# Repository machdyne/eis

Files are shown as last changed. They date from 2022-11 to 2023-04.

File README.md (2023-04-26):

# Eis Computer

Eis is a small FPGA computer designed by Lone Dynamics Corporation.

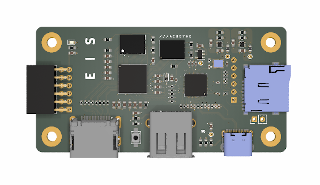
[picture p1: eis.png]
Eis Computer


This repo contains schematics, PCB layouts, pinouts, example firmware, gateware, documentation and a 3D printable case.

Find more information on the [Eis product page](https://machdyne.com/product/eis-computer/).

## Blinky 

Building the blinky example requires [Yosys](https://github.com/YosysHQ/yosys), [nextpnr-ice40](https://github.com/YosysHQ/nextpnr) and [IceStorm](https://github.com/YosysHQ/icestorm).

Assuming they are installed, you can simply type `make` to build the gateware, which will be written to output/blinky.bin. You can then connect the USB-C port to your computer and use the latest version of [ldprog](https://github.com/machdyne/ldprog) to write the gateware to the device.

## Programming

The RP2040 firmware, FPGA SRAM and flash MMOD can be programmed over the USB-C port.

Configure the FPGA SRAM:

```
$ ldprog -i -s blinky.bin
```

Program the flash MMOD:

```
$ ldprog -i -f blinky.bin
```

## Firmware

Eis ships with RP2040 [firmware](firmware) based on the [Müsli](https://github.com/machdyne/musli) firmware which allows it to communicate with [ldprog](https://github.com/machdyne/ldprog).

The firmware is responsible for initializing the system, [configuring and outputting the system clock](https://raspberrypi.github.io/pico-sdk-doxygen/group__hardware__clocks.html#details), and either configuring the FPGA or telling the FPGA to configure itself from the MMOD.

The system clock (CLK\_RP) is 48MHz by default.

The firmware can be updated by holding down the BOOTSEL button, connecting the USB-C port to your computer, and then dragging and dropping a new UF2 file to the device filesystem.

The firmware can be built from source or you can use the latest `eis.uf2` binary from the firmware directory.

## SOC

[Zucker](https://github.com/machdyne/zucker) is an experimental RISC-V SOC that supports Eis.

## Pinouts

 * [MMOD](https://github.com/machdyne/mmod)
 * [DDMI](https://github.com/machdyne/ddmi)

## License

The contents of this repo are released under the [Lone Dynamics Open License](LICENSE.md) with the following exceptions:

- The KiCad design files contain parts of the [kicad-pmod](https://github.com/mithro/kicad-pmod) library which is released under the [Apache License, Version 2.0](https://www.apache.org/licenses/LICENSE-2.0.html).

- The KiCad design files may contain symbols and footprints released under other licenses; please contact us if we've failed to give proper attribution.

Note: You can use these designs for commercial purposes but we ask that instead of producing exact clones, that you either replace our trademarks and logos with your own or add your own next to ours.

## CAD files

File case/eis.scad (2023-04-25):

/*
 * Eis Case
 * Copyright (c) 2022 Lone Dynamics Corporation. All rights reserved.
 *
 * required hardware:
 *  - 4 x M3 x 16mm countersunk bolts
 *  - 4 x M3 nuts
 *
 */

$fn = 100;

board_width = 40;
board_thickness = 1.5;
board_length = 80;
board_height = 1.6;
board_spacing = 2;

wall = 1.5;

top_height = 9;
bottom_height = 8;

//ldn_board();

translate([0,0,15])
	ldn_case_top();

//translate([0,0,-15])
//	ldn_case_bottom();

module ldn_board() {
	
	difference() {
		color([0,0.5,0])
			roundedcube(board_width,board_length,board_thickness, 2);
		translate([5, 5, -1]) cylinder(d=3.2, h=10);
		translate([5, 75, -1]) cylinder(d=3.2, h=10);
		translate([35, 5, -1]) cylinder(d=3.2, h=10);
		translate([35, 75, -1]) cylinder(d=3.2, h=10);
	}	
	
}

module ldn_case_top() {
	
	difference() {
				
		color([0.5,0.5,0.5])
			roundedcube(board_width+(wall*2),board_length+(wall*2),top_height,2.5);

		// cutouts
			
		translate([2,9,-2])
			roundedcube(board_width-1.25,board_length-15,9.25,2.5);

		translate([9,3,-2])
			roundedcube(board_width-15,board_length-3,9.25,2.5);
		
		translate([wall, wall, 0]) {
	
			// HDMI
			translate([30,19-(15.5/2),-1]) cube([30,15.5,6.2+1]);
		
			// USBA
			translate([30,43-(15/2),-1]) cube([30,15,7.2+1.05]);

			// USBC
			translate([30,64.25-(9.5/2),-1]) cube([30,9.5,3.5+1]);
		
			// SD
			translate([20-(15/2),70,-1]) cube([15,30,2+1]);

			// PMODA
			translate([20-(16/2),-10,-2]) cube([16,30,5.5+1.15]);

			// LED vent
			// translate([-5,25,4]) cube([30,1.5,1.5]);
			// translate([-5,20,4]) cube([30,1.5,1.5]);
			// translate([-5,15,4]) cube([30,1.5,1.5]);
				
			// bolt holes
			translate([5, 5, -21]) cylinder(d=3.5, h=40);
			translate([5, 75, -21]) cylinder(d=3.5, h=40);
			translate([35, 5, -20]) cylinder(d=3.5, h=40);
			translate([35, 75, -21]) cylinder(d=3.5, h=40);

			// flush mount bolt holes
			translate([5, 5, top_height-1]) cylinder(d=5, h=4);
			translate([5, 75, top_height-1]) cylinder(d=5, h=4);
			translate([35, 5, top_height-1]) cylinder(d=5, h=4);
			translate([35, 75, top_height-1]) cylinder(d=5, h=4);

			// eis text
			rotate(270)
				translate([-21,20-3,top_height-0.8])
					linear_extrude(1)
						text("E   I   S", size=6, halign="center",
							font="Ubuntu:style=Bold");

		}
		
	}	
}

module ldn_case_bottom() {
	
	difference() {
		color([0.5,0.5,0.5])
			roundedcube(board_width+(wall*2),board_length+(wall*2),bottom_height,2.5);
		
		// cutouts
		translate([3,10,1.5])
			roundedcube(board_width-3,board_length-17,10,2.5);
				
		translate([10.5,2.5,1.5])
			roundedcube(board_width-17.5,board_length-2,10,2.5);

		translate([wall, wall, 0]) {
			
		// board cutout
		translate([-0.25,-0.25,bottom_height-board_height])
			roundedcube(board_width+0.5,board_length+0.5,board_height+1,2);

		// bolt holes
		translate([5, 5, -11]) cylinder(d=3.2, h=25);
		translate([5, 75, -11]) cylinder(d=3.2, h=25);
		translate([35, 5, -11]) cylinder(d=3.2, h=25);
		translate([35, 75, -11]) cylinder(d=3.2, h=25);

		// nut holes
		translate([5, 5, -1]) cylinder(d=7, h=2.5+2, $fn=6);
		translate([5, 75, -1]) cylinder(d=7, h=2.5+2, $fn=6);
		translate([35, 5, -1]) cylinder(d=7, h=2.5+2, $fn=6);
		translate([35, 75, -1]) cylinder(d=7, h=2.5+2, $fn=6);

		}
		
	}	
}

// https://gist.github.com/tinkerology/ae257c5340a33ee2f149ff3ae97d9826
module roundedcube(xx, yy, height, radius)
{
    translate([0,0,height/2])
    hull()
    {
        translate([radius,radius,0])
        cylinder(height,radius,radius,true);

        translate([xx-radius,radius,0])
        cylinder(height,radius,radius,true);

        translate([xx-radius,yy-radius,0])
        cylinder(height,radius,radius,true);

        translate([radius,yy-radius,0])
        cylinder(height,radius,radius,true);
    }
}

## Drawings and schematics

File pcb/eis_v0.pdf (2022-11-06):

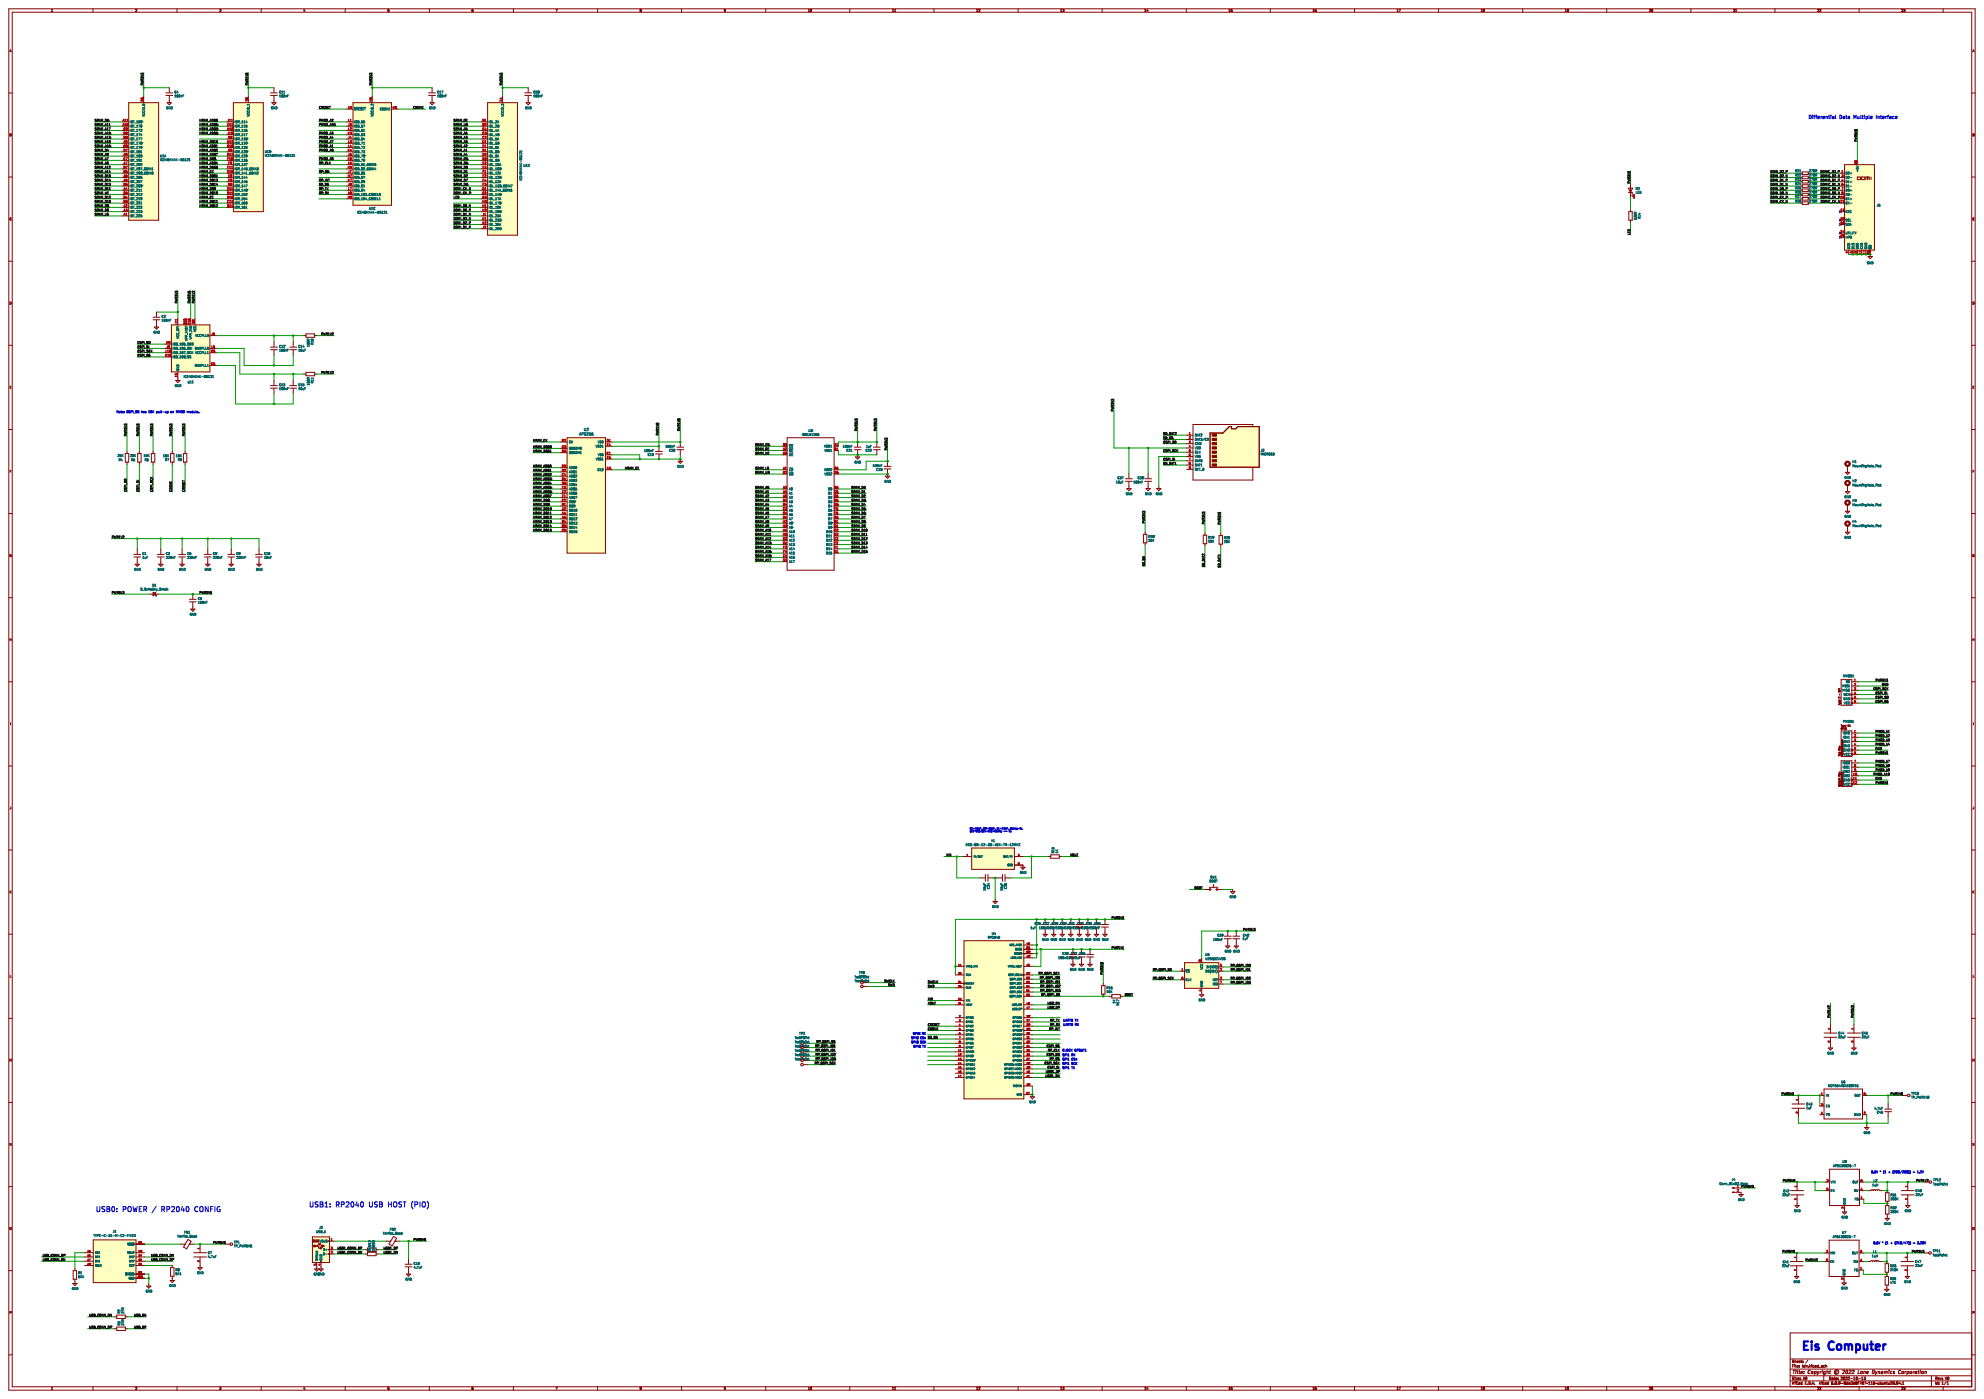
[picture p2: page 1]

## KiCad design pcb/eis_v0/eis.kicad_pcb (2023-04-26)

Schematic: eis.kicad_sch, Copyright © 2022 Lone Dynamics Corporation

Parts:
C1, C43: 1uF; C_0603_1608Metric
C2, C4, C6, C11, C12, C13, C17, C18: 100nF; C_0603_1608Metric
C3, C5, C8, C9: 220nF; C_0603_1608Metric
C7, C16: 4.7uF; C_0603_1608Metric
C10: 10nF; C_0603_1608Metric
C14, C15: 10uF; C_0603_1608Metric
C19, C20, C21, C23: 100nF; R_0603_1608Metric
C22: 1uF; R_0603_1608Metric
C24, C25: 15pF; C_0402_1005Metric
C26, C34, C40: 1uF; C_0402_1005Metric
C27, C28, C29, C30, C31, C32, C33, C35, C36, C39: 100nF; C_0402_1005Metric
C37: 10uF; R_0402_1005Metric
C38: 100nF; R_0402_1005Metric
C41, C42, C44, C46, C47, C48: 22uF; C_0603_1608Metric
C45: 4.7uF; R_0603_1608Metric
D1: D_Schottky_Small; D_0603_1608Metric
D2: LED; LED_0603_1608Metric
FB1, FB2: Ferrite_Bead; R_0603_1608Metric
H1, H2, H3, H4: MountingHole_Pad; MountingHole_3.2mm_M3_Pad
J1: TYPE-C-31-M-12-FIXED; USB_C_Receptacle_HRO_TYPE-C-31-M-12; PARTREV A
J2: USB_A; USB_A_Stewart_SS-52100-001_Horizontal
J3: MICROSD; SDCARD
J4: Conn_01x02_Male; PinHeader_1x02_P2.54mm_Vertical
J5: HDMI_TE_1827059-3-FIXED
L1, L2: 1uH; L_0603_1608Metric
MMOD1: PMOD-Device-x1-Type-2-SPI; PinSocket_1x06_P2.54mm_Horizontal
PMOD1: PMOD-Device-x2-Type-1A-GPIO; PMOD_2x06_HOST
R1, R8: 5K1; R_0603_1608Metric
R2, R3: 27R; R_0402_1005Metric
R4, R5, R18, R19, R20: 20K; R_0402_1005Metric
R6, R7, R9, R16: 10K; R_0402_1005Metric
R10, R11: 100R; R_0603_1608Metric
R12, R13: 22R; R_0402_1005Metric
R14: 536R; R_0603_1608Metric
R15: 1K; R_0402_1005Metric
R17: 1K; R_0603_1608Metric
R21, R22, R23, R24, R25, R26, R27, R28: 270R; R_0402_1005Metric
R29: 210K; R_0603_1608Metric
R30: 47K; R_0603_1608Metric
R31, R32: 200K; R_0603_1608Metric
SW1: BOOT; Button_2P_3x4mm
TP1: TP_PWR5V0; TestPoint_THTPad_D1.0mm_Drill0.5mm
TP2, TP3, TP4, TP5, TP6, TP7, TP8, TP9: TestPoint; TestPoint_Pad_1.0x1.0mm
TP10: TP_PWR1V8; TestPoint_THTPad_D1.0mm_Drill0.5mm
TP11, TP12: TestPoint; TestPoint_THTPad_D1.0mm_Drill0.5mm
U1: ICE40HX4K-BG121; BGA-121_9.0x9.0mm_Layout11x11_P0.8mm_Ball0.4mm_Pad0.35mm_NS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
U2: APS256; APS256_BGA_24
U3: IS61WV256; BGA48C75P8X6_800X600X120N
U4: RP2040; RP2040-QFN-56-OFFICIAL; PARTREV 1.6.1
U5: W25Q32JVSS; SOIC-8_3.9x4.9mm_P1.27mm
U6: NCP164ASN180T1G; TSOP-5_1.65x3.05mm_P0.95mm
U7, U8: AP61300Z6-7; SOT-563
Y1: ECS-80-12-33-JGN-TR-12MHZ; XTAL_ECS-240-8-33-AGN-TR

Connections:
/BOOT: R17.1, SW1.1
/CDONE: R7.1, U1.K8 (CDONE), U4.5 (GPIO3)
/CRESET: R9.1, U1.L9 (~CRESET), U4.4 (GPIO2)
/CSPI_SCK: J3.5 (CLK), MMOD1.3 (MISO), R6.1, U1.L10 (IOB_107_SCK), U4.38 (GPIO26/ADC0)
/CSPI_SI: J3.7 (DAT0), MMOD1.4 (SCK), R5.1, U1.J9 (IOB_106_SDI), U4.39 (GPIO27/ADC1)
/CSPI_SO: J3.3 (CMD), MMOD1.5 (GND), R4.1, U1.K9 (IOB_105_SDO), U4.36 (GPIO24)
/CSPI_SS: MMOD1.6 (VCC), U1.K10 (IOB_108_SS), U4.34 (GPIO22)
/DDMIC_CK_N: J5.12 (CK-), R28.2
/DDMIC_CK_P: J5.10 (CK+), R27.2
/DDMIC_D0_N: J5.9 (D0-), R26.2
/DDMIC_D0_P: J5.7 (D0+), R25.2
/DDMIC_D1_N: J5.6 (D1-), R24.2
/DDMIC_D1_P: J5.4 (D1+), R23.2
/DDMIC_D2_N: J5.3 (D2-), R22.2
/DDMIC_D2_P: J5.1 (D2+), R21.2
/DDMI_CK_N: R28.1, U1.G1 (IOL_14A_GBIN6)
/DDMI_CK_P: R27.1, U1.G2 (IOL_14B)
/DDMI_D0_N: R26.1, U1.H1 (IOL_18A)
/DDMI_D0_P: R25.1, U1.H2 (IOL_18B)
/DDMI_D1_N: R24.1, U1.J1 (IOL_23A)
/DDMI_D1_P: R23.1, U1.J2 (IOL_25B)
/DDMI_D2_N: R22.1, U1.K1 (IOL_23B)
/DDMI_D2_P: R21.1, U1.K2 (IOL_25A)
/HRAM_ADQ0: U1.J11 (IOR_114), U2.D3 (ADQ0)
/HRAM_ADQ1: U1.G10 (IOR_120), U2.D2 (ADQ1)
/HRAM_ADQ2: U1.G9 (IOR_128), U2.C4 (ADQ2)
/HRAM_ADQ3: U1.H10 (IOR_116), U2.D4 (ADQ3)
/HRAM_ADQ4: U1.F9 (IOR_137), U2.D5 (ADQ4)
/HRAM_ADQ5: U1.K11 (IOR_115), U2.E3 (ADQ5)
/HRAM_ADQ6: U1.J10 (IOR_117), U2.E2 (ADQ6)
/HRAM_ADQ7: U1.G11 (IOR_129), U2.E1 (ADQ7)
/HRAM_CE: U1.D10 (IOR_154), U2.A3 (CE#)
/HRAM_CK: U1.E10 (IOR_141_GBIN2), U2.B2 (CK)
/HRAM_DQ8: U1.F10 (IOR_136), U2.C2 (DQ8)
/HRAM_DQ9: U1.E11 (IOR_148), U2.B1 (DQ9)
/HRAM_DQ10: U1.D11 (IOR_152), U2.A2 (DQ10)
/HRAM_DQ11: U1.C11 (IOR_160), U2.A4 (DQ11)
/HRAM_DQ12: U1.B11 (IOR_161), U2.A5 (DQ12)
/HRAM_DQ13: U1.E8 (IOR_146), U2.B4 (DQ13)
/HRAM_DQ14: U1.D9 (IOR_147), U2.B5 (DQ14)
/HRAM_DQ15: U1.H11 (IOR_119), U2.C5 (DQ15)
/HRAM_DQS0: U1.F11 (IOR_140_GBIN3), U2.C3 (DQSDM0)
/HRAM_DQS1: U1.E9 (IOR_144), U2.B3 (DQSDM1)
/LED: R14.1, U1.G3 (IOL_17A)
/PMOD_A1: PMOD1.1 (IOA0), U1.L4 (IOB_72)
/PMOD_A2: PMOD1.2 (IOA1), U1.L1 (IOB_56)
/PMOD_A3: PMOD1.3 (IOA2), U1.K3 (IOB_63)
/PMOD_A4: PMOD1.4 (IOA3), U1.J4 (IOB_64)
/PMOD_A7: PMOD1.7 (IOB0), U1.L3 (IOB_71)
/PMOD_A8: PMOD1.8 (IOB1), U1.K5 (IOB_79)
/PMOD_A9: PMOD1.9 (IOB2), U1.K4 (IOB_73)
/PMOD_A10: PMOD1.10 (IOB3), U1.J3 (IOB_57)
/PWR1V1: C30.1, C32.1, C34.1, U4.23 (DVDD), U4.45 (VREG_VOUT), U4.50 (DVDD)
/PWR1V2: C1.1, C3.1, C5.1, C8.1, C9.1, C10.1, C44.1, C48.1, L2.2, R10.1, R11.1, R31.1, TP12.1, U1.D4 (VCC), U1.D8 (VCC), U1.H4 (VCC), U1.H8 (VCC), U7.5 (EN), U8.6 (OUT)
/PWR1V8: C11.1, C19.2, C20.2, C45.2, TP10.1, U1.F8 (VCCIO_1), U2.D1 (VDD), U2.E4 (VDD1), U6.5 (OUT)
/PWR2V5: C6.1, D1.1 (K), U1.C10 (VPP_2V5)
/PWR3V3: C2.1, C4.1, C17.1, C18.1, C21.2, C22.2, C23.2, C26.1, C27.1, C28.1, C29.1, C31.1, C33.1, C35.1, C36.1, C37.1, C38.1, C39.1, C40.1, C43.1, C46.1, C47.1, D1.2 (A), D2.2 (A), J3.4 (VDD), L1.2, MMOD1.1 (SS), PMOD1.6 (VCC), PMOD1.12 (VCC), R4.2, R5.2, R6.2, R7.2, R9.2, R16.1, R18.1, R19.1, R20.1, R29.1, TP11.1, U1.D6 (VCCIO_0), U1.E4 (VCCIO_3), U1.G4 (VCCIO_3), U1.H6 (VCCIO_2), U1.L11 (VCC_SPI), U3.D6 (VDD2), U3.E1 (VDD1), U4.1 (IOVDD), U4.10 (IOVDD), U4.22 (IOVDD), U4.26 (RUN), U4.33 (IOVDD), U4.42 (IOVDD), U4.43 (ADC_AVDD), U4.44 (VREG_VIN), U4.48 (USB_VDD), U4.49 (IOVDD), U5.8 (VCC), U6.1 (IN), U6.3 (EN), U7.6 (OUT)
/PWR5V0: C7.1, C16.1, C41.1, C42.1, FB1.1, FB2.1, J4.1, J5.18 (+5V), TP1.1, U7.3 (VIN), U8.3 (VIN), U8.5 (EN)
/RP_CLK: U1.L5 (IOB_81_GBIN5), U4.35 (GPIO23)
/RP_INT: U1.K7 (IOB_89), U4.29 (GPIO18)
/RP_QSPI_IO0: TP3.1, U4.53 (QSPI_SD0), U5.5 (DI(IO0))
/RP_QSPI_IO1: TP4.1, U4.55 (QSPI_SD1), U5.2 (DO(IO1))
/RP_QSPI_IO2: TP5.1, U4.54 (QSPI_SD2), U5.3 (IO2)
/RP_QSPI_IO3: TP6.1, U4.51 (QSPI_SD3), U5.7 (IO3)
/RP_QSPI_SCK: TP7.1, U4.52 (QSPI_SCLK), U5.6 (CLK)
/RP_QSPI_SS: R16.2, R17.2, TP2.1, U4.56 (QSPI_CSN), U5.1 (~CS)
/RP_RX: U1.L8 (IOB_103_CBSEL0), U4.28 (GPIO17)
/RP_SS: U1.J7 (IOB_86), U4.37 (GPIO25)
/RP_TX: U1.L7 (IOB_94), U4.27 (GPIO16)
/SD_DAT1: J3.8 (DAT1), R20.2
/SD_DAT2: J3.1 (DAT2), R19.2
/SD_SS: J3.2 (DAT3/CD), R18.2, U1.J8 (IOB_91), U4.7 (GPIO5)
/SRAM_A0: U1.C1 (IOL_5B), U3.A3 (A0)
/SRAM_A1: U1.D1 (IOL_8B), U3.A4 (A1)
/SRAM_A2: U1.E1 (IOL_8A), U3.A5 (A2)
/SRAM_A3: U1.C2 (IOL_5A), U3.B3 (A3)
/SRAM_A4: U1.D2 (IOL_9A), U3.B4 (A4)
/SRAM_A5: U1.C4 (IOL_4A), U3.C3 (A5)
/SRAM_A6: U1.C3 (IOL_4B), U3.C4 (A6)
/SRAM_A7: U1.C7 (IOT_191), U3.D4 (A7)
/SRAM_A8: U1.A7 (IOT_192), U3.H2 (A8)
/SRAM_A9: U1.A8 (IOT_190), U3.H3 (A9)
/SRAM_A10: U1.A9 (IOT_178), U3.H4 (A10)
/SRAM_A11: U1.A10 (IOT_170), U3.H5 (A11)
/SRAM_A12: U1.B7 (IOT_197_GBIN1), U3.G3 (A12)
/SRAM_A13: U1.B8 (IOT_177), U3.G4 (A13)
/SRAM_A14: U1.B6 (IOT_198_GBIN0), U3.F3 (A14)
/SRAM_A15: U1.B9 (IOT_174), U3.F4 (A15)
/SRAM_A16: U1.C8 (IOT_179), U3.E4 (A16)
/SRAM_A17: U1.C9 (IOT_172), U3.D3 (A17)
/SRAM_CS: U1.D3 (IOL_9B), U3.B5 (~CS)
/SRAM_D0: U1.E3 (IOL_10B), U3.B6 (D0)
/SRAM_D1: U1.F1 (IOL_12A), U3.C5 (D1)
/SRAM_D2: U1.F2 (IOL_12B), U3.C6 (D2)
/SRAM_D3: U1.F3 (IOL_13B_GBIN7), U3.D5 (D3)
/SRAM_D4: U1.D7 (IOT_181), U3.E5 (D4)
/SRAM_D5: U1.E2 (IOL_10A), U3.F5 (D5)
/SRAM_D6: U1.A11 (IOT_168), U3.F6 (D6)
/SRAM_D7: U1.F4 (IOL_13A), U3.G6 (D7)
/SRAM_D8: U1.A2 (IOT_222), U3.B1 (D8)
/SRAM_D9: U1.A3 (IOT_223), U3.C1 (D9)
/SRAM_D10: U1.B3 (IOT_221), U3.C2 (D10)
/SRAM_D11: U1.A4 (IOT_211), U3.D2 (D11)
/SRAM_D12: U1.B4 (IOT_219), U3.E2 (D12)
/SRAM_D13: U1.B5 (IOT_208), U3.F2 (D13)
/SRAM_D14: U1.A5 (IOT_207), U3.F1 (D14)
/SRAM_D15: U1.A6 (IOT_206), U3.G1 (D15)
/SRAM_LB: U1.A1 (IOT_225), U3.A1 (~LB)
/SRAM_OE: U1.B1 (IOL_2A), U3.A2 (~OE)
/SRAM_UB: U1.B2 (IOL_2B), U3.B2 (~UB)
/SRAM_WE: U1.D5 (IOT_212), U3.G5 (~WE)
/SWCLK: TP8.1, U4.24 (SWCLK)
/SWD: TP9.1, U4.25 (SWD)
/USB1_CONN_DN: J2.2 (D-), R13.1
/USB1_CONN_DP: J2.3 (D+), R12.1
/USB1_DN: R13.2, U4.41 (GPIO29/ADC3)
/USB1_DP: R12.2, U4.40 (GPIO28/ADC2)
/USB_CONN_DN: J1.A7 (DN1), J1.B7 (DN2), R2.1
/USB_CONN_DP: J1.A6 (DP1), J1.B6 (DP2), R3.1
/USB_DN: R2.2, U4.46 (USB_DM)
/USB_DP: R3.2, U4.47 (USB_DP)
/XIN: C24.2, U4.20 (XIN), Y1.1 (IN/OUT)
/XOUT: R15.2, U4.21 (XOUT)
GND: C1.2, C2.2, C3.2, C4.2, C5.2, C6.2, C7.2, C8.2, C9.2, C10.2, C11.2, C16.2, C17.2, C18.2, C19.1, C20.1, C21.1, C22.1, C23.1, C24.1, C25.2, C26.2, C27.2, C28.2, C29.2, C30.2, C31.2, C32.2, C33.2, C34.2, C35.2, C36.2, C37.2, C38.2, C39.2, C40.2, C41.2, C42.2, C43.2, C44.2, C45.1, C46.2, C47.2, C48.2, H1.1, H2.1, H3.1, H4.1, J1.A1 (GND), J1.A12 (GND), J1.B1 (GND), J1.B12 (GND), J1.S1 (SHIELD), J1.S2 (SHIELD), J1.S3 (SHIELD), J1.S4 (SHIELD), J2.4 (GND), J2.5 (Shield), J3.6 (VSS), J4.2, J5.2 (D2S), J5.5 (D1S), J5.8 (D0S), J5.11 (CKS), J5.17 (GND), J5.S1 (SH), J5.S2 (SH), J5.S3 (SH), J5.S4 (SH), MMOD1.2 (MOSI), PMOD1.5 (GND), PMOD1.11 (GND), R1.2, R8.2, R30.2, R32.2, SW1.2, U1.E5 (GND), U1.E6 (GND), U1.E7 (GND), U1.F5 (GND), U1.F6 (GND), U1.F7 (GND), U1.G5 (GND), U1.G6 (GND), U1.G7 (GND), U1.H5 (GND), U2.C1 (VSS), U2.E5 (VSS1), U3.D1 (VSS1), U3.E6 (VSS2), U4.19 (TESTEN), U4.57 (GND), U5.4 (GND), U6.2 (GND), U7.2 (GND), U8.2 (GND), Y1.2 (GND), Y1.4 (GND)
unnamed: C12.1, C14.1, R10.2, U1.J6 (VCCPLL0)
unnamed: C12.2, C14.2, U1.L6 (GNDPLL0)
unnamed: C13.1, C15.1, R11.2, U1.C6 (VCCPLL1)
unnamed: C13.2, C15.2, U1.C5 (GNDPLL1)
unnamed: C25.1, R15.1, Y1.3 (OUT/IN)
unnamed: D2.1 (K), R14.2
unnamed: FB1.2, J1.A4 (VBUS), J1.A9 (VBUS), J1.B4 (VBUS), J1.B9 (VBUS)
unnamed: FB2.2, J2.1 (VBUS)
unnamed: J1.A5 (CC1), R1.1
unnamed: J1.B5 (CC2), R8.1
unnamed: L1.1, U7.4 (SW)
unnamed: L2.1, U8.4 (SW)
unnamed: R29.2, R30.1, U7.1 (FB)
unnamed: R31.2, R32.1, U8.1 (FB)

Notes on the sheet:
SPI1 RX
CLOCK GPOUT1
UART0 RX
USB1: RP2040 USB HOST (PIO)
0.6V * (1 + (210/47)) = 3.28V
SPI1 CSn
C1=15pF, C2=15pF, CL=12pF, Cstray=5, (C1*C2)/(C1+C2)+Cstray == CL
SPI0 CSn
UART0 TX
0.6V * (1 + (200/200)) = 1.2V
Differential Data Multiple Interface
USB0: POWER / RP2040 CONFIG
SPI0 TX
SPI1 TX
Note: CSPI_SS has 10K pull-up on MMOD module.
SPI0 RX
SPI1 SCK
SPI0 SCK
Eis Computer

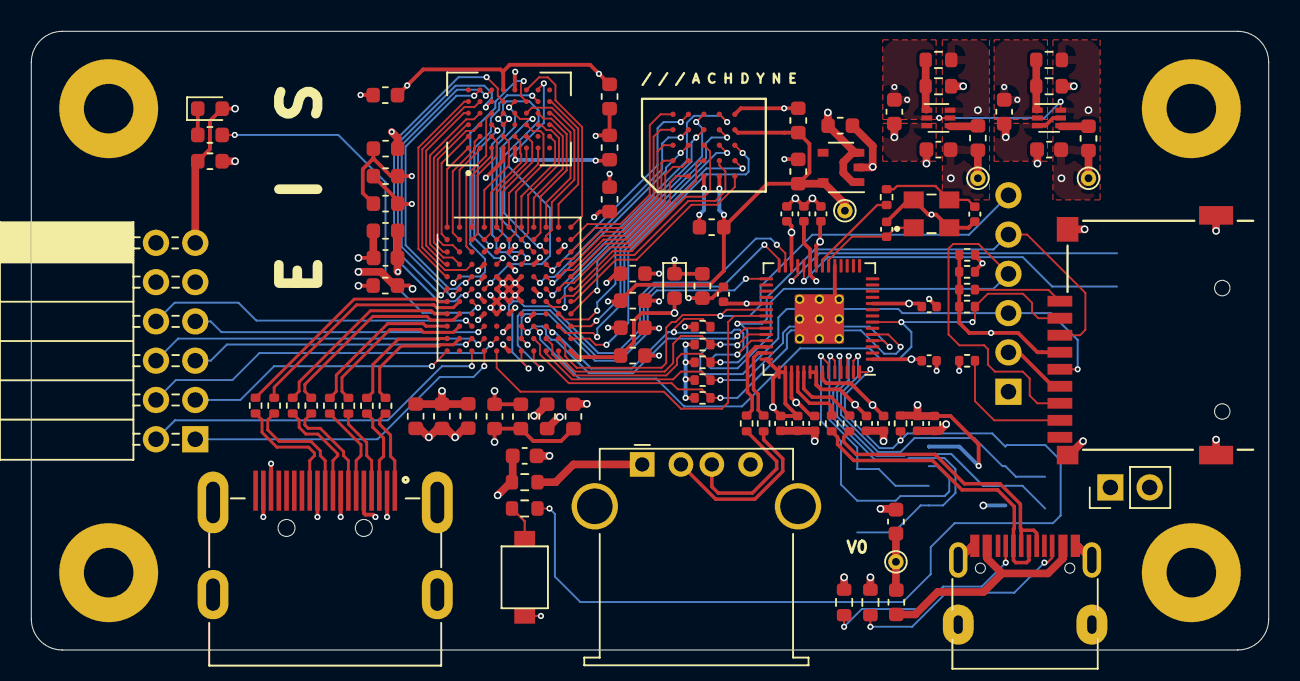
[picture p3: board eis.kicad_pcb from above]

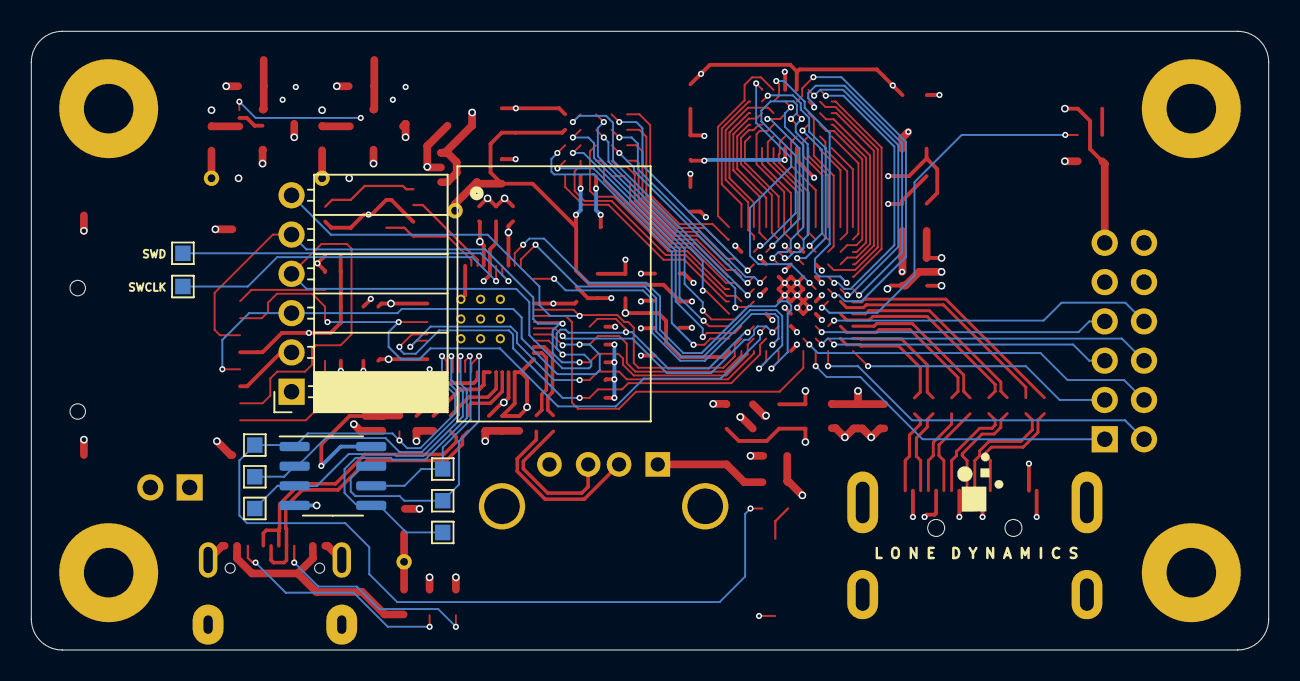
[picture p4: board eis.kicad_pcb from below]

Board: 4 copper layers, 80.0 x 40.0 mm, 120 parts (11 on the bottom side), 138 nets.

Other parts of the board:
CONFIG-MMOD: LD-MMOD

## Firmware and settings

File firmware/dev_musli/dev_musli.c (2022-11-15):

/**
 * Copyright (c) 2020 Raspberry Pi (Trading) Ltd.
 * Copyright (c) 2022 Lone Dynamics Corporation <info@lonedynamics.com>
 *
 * SPDX-License-Identifier: BSD-3-Clause
 *
 * Musli USB Device Software
 *
 */

#define MUSLI_SPI_RX_PIN	24
#define MUSLI_SPI_CSN_PIN	22
#define MUSLI_SPI_SCK_PIN	26
#define MUSLI_SPI_TX_PIN	27

#define MUSLI_CMD_READY 0x00
#define MUSLI_CMD_INIT 0x01

#define MUSLI_CMD_GPIO_SET_DIR 0x10
#define MUSLI_CMD_GPIO_DISABLE_PULLS 0x11
#define MUSLI_CMD_GPIO_PULL_UP 0x12
#define MUSLI_CMD_GPIO_PULL_DOWN 0x13

#define MUSLI_CMD_GPIO_GET 0x20
#define MUSLI_CMD_GPIO_PUT 0x21

#define MUSLI_CMD_SPI_READ 0x80
#define MUSLI_CMD_SPI_WRITE 0x81
#define MUSLI_CMD_CFG_PIO_SPI 0x8f

#define MUSLI_CMD_REBOOT 0xf0

#define SPI_MODE_HW 1
#define SPI_MODE_PIO 2

#include <stdio.h>
#include <strings.h>

// Pico
#include "pico/stdlib.h"
#include "hardware/spi.h"
#include "hardware/watchdog.h"
#include "pico/stdlib.h"
#include "pico/binary_info.h"
#include "pio_spi.h"

uint8_t spi_mode = SPI_MODE_HW;

void init_ldprog(void);
void init_gpio(void);
void init_pio_spi(void);
void pio_spi_cfg(uint8_t pin_sck, uint8_t pin_mosi, uint8_t pin_miso);

uint8_t spi_pio_offset;

pio_spi_inst_t spi_pio = {
	.pio = pio0,
	.sm = 0
};

// For memcpy
#include <string.h>

// Include descriptor struct definitions
#include "usb_common.h"
// USB register definitions from pico-sdk
#include "hardware/regs/usb.h"
// USB hardware struct definitions from pico-sdk
#include "hardware/structs/usb.h"
// For interrupt enable and numbers
#include "hardware/irq.h"
// For resetting the USB controller
#include "hardware/resets.h"

// Device descriptors
#include "dev_musli.h"

#define usb_hw_set hw_set_alias(usb_hw)
#define usb_hw_clear hw_clear_alias(usb_hw)

// Function prototypes for our device specific endpoint handlers defined
// later on
void ep0_in_handler(uint8_t *buf, uint16_t len);
void ep0_out_handler(uint8_t *buf, uint16_t len);
void ep1_out_handler(uint8_t *buf, uint16_t len);
void ep2_in_handler(uint8_t *buf, uint16_t len);

// Global device address
static bool should_set_address = false;
static uint8_t dev_addr = 0;
static volatile bool configured = false;

// Global data buffer for EP0
static uint8_t ep0_buf[64];

// Struct defining the device configuration
static struct usb_device_configuration dev_config = {
        .device_descriptor = &device_descriptor,
        .interface_descriptor = &interface_descriptor,
        .config_descriptor = &config_descriptor,
        .lang_descriptor = lang_descriptor,
        .descriptor_strings = descriptor_strings,
        .endpoints = {
                {
                        .descriptor = &ep0_out,
                        .handler = &ep0_out_handler,
                        .endpoint_control = NULL, // NA for EP0
                        .buffer_control = &usb_dpram->ep_buf_ctrl[0].out,
                        // EP0 in and out share a data buffer
                        .data_buffer = &usb_dpram->ep0_buf_a[0],
                },
                {
                        .descriptor = &ep0_in,
                        .handler = &ep0_in_handler,
                        .endpoint_control = NULL, // NA for EP0,
                        .buffer_control = &usb_dpram->ep_buf_ctrl[0].in,
                        // EP0 in and out share a data buffer
                        .data_buffer = &usb_dpram->ep0_buf_a[0],
                },
                {
                        .descriptor = &ep1_out,
                        .handler = &ep1_out_handler,
                        // EP1 starts at offset 0 for endpoint control
                        .endpoint_control = &usb_dpram->ep_ctrl[0].out,
                        .buffer_control = &usb_dpram->ep_buf_ctrl[1].out,
                        // First free EPX buffer
                        .data_buffer = &usb_dpram->epx_data[0 * 64],
                },
                {
                        .descriptor = &ep2_in,
                        .handler = &ep2_in_handler,
                        .endpoint_control = &usb_dpram->ep_ctrl[1].in,
                        .buffer_control = &usb_dpram->ep_buf_ctrl[2].in,
                        // Second free EPX buffer
                        .data_buffer = &usb_dpram->epx_data[1 * 64],
                }
        }
};

/**
 * @brief Given an endpoint address, return the usb_endpoint_configuration of that endpoint. Returns NULL
 * if an endpoint of that address is not found.
 *
 * @param addr
 * @return struct usb_endpoint_configuration*
 */
struct usb_endpoint_configuration *usb_get_endpoint_configuration(uint8_t addr) {
    struct usb_endpoint_configuration *endpoints = dev_config.endpoints;
    for (int i = 0; i < USB_NUM_ENDPOINTS; i++) {
        if (endpoints[i].descriptor && (endpoints[i].descriptor->bEndpointAddress == addr)) {
            return &endpoints[i];
        }
    }
    return NULL;
}

/**
 * @brief Given a C string, fill the EP0 data buf with a USB string descriptor for that string.
 *
 * @param C string you would like to send to the USB host
 * @return the length of the string descriptor in EP0 buf
 */
uint8_t usb_prepare_string_descriptor(const unsigned char *str) {
    // 2 for bLength + bDescriptorType + strlen * 2 because string is unicode. i.e. other byte will be 0
    uint8_t bLength = 2 + (strlen((const char *)str) * 2);
    static const uint8_t bDescriptorType = 0x03;

    volatile uint8_t *buf = &ep0_buf[0];
    *buf++ = bLength;
    *buf++ = bDescriptorType;

    uint8_t c;

    do {
        c = *str++;
        *buf++ = c;
        *buf++ = 0;
    } while (c != '\0');

    return bLength;
}

/**
 * @brief Take a buffer pointer located in the USB RAM and return as an offset of the RAM.
 *
 * @param buf
 * @return uint32_t
 */
static inline uint32_t usb_buffer_offset(volatile uint8_t *buf) {
    return (uint32_t) buf ^ (uint32_t) usb_dpram;
}

/**
 * @brief Set up the endpoint control register for an endpoint (if applicable. Not valid for EP0).
 *
 * @param ep
 */
void usb_setup_endpoint(const struct usb_endpoint_configuration *ep) {
    printf("Set up endpoint 0x%x with buffer address 0x%p\n", ep->descriptor->bEndpointAddress, ep->data_buffer);

    // EP0 doesn't have one so return if that is the case
    if (!ep->endpoint_control) {
        return;
    }

    // Get the data buffer as an offset of the USB controller's DPRAM
    uint32_t dpram_offset = usb_buffer_offset(ep->data_buffer);
    uint32_t reg = EP_CTRL_ENABLE_BITS
                   | EP_CTRL_INTERRUPT_PER_BUFFER
                   | (ep->descriptor->bmAttributes << EP_CTRL_BUFFER_TYPE_LSB)
                   | dpram_offset;
    *ep->endpoint_control = reg;
}

/**
 * @brief Set up the endpoint control register for each endpoint.
 *
 */
void usb_setup_endpoints() {
    const struct usb_endpoint_configuration *endpoints = dev_config.endpoints;
    for (int i = 0; i < USB_NUM_ENDPOINTS; i++) {
        if (endpoints[i].descriptor && endpoints[i].handler) {
            usb_setup_endpoint(&endpoints[i]);
        }
    }
}

/**
 * @brief Set up the USB controller in device mode, clearing any previous state.
 *
 */
void usb_device_init() {
    // Reset usb controller
    reset_block(RESETS_RESET_USBCTRL_BITS);
    unreset_block_wait(RESETS_RESET_USBCTRL_BITS);

    // Clear any previous state in dpram just in case
    memset(usb_dpram, 0, sizeof(*usb_dpram)); // <1>

    // Enable USB interrupt at processor
    irq_set_enabled(USBCTRL_IRQ, true);

    // Mux the controller to the onboard usb phy
    usb_hw->muxing = USB_USB_MUXING_TO_PHY_BITS | USB_USB_MUXING_SOFTCON_BITS;

    // Force VBUS detect so the device thinks it is plugged into a host
    usb_hw->pwr = USB_USB_PWR_VBUS_DETECT_BITS | USB_USB_PWR_VBUS_DETECT_OVERRIDE_EN_BITS;

    // Enable the USB controller in device mode.
    usb_hw->main_ctrl = USB_MAIN_CTRL_CONTROLLER_EN_BITS;

    // Enable an interrupt per EP0 transaction
    usb_hw->sie_ctrl = USB_SIE_CTRL_EP0_INT_1BUF_BITS; // <2>

    // Enable interrupts for when a buffer is done, when the bus is reset,
    // and when a setup packet is received
    usb_hw->inte = USB_INTS_BUFF_STATUS_BITS |
                   USB_INTS_BUS_RESET_BITS |
                   USB_INTS_SETUP_REQ_BITS;

    // Set up endpoints (endpoint control registers)
    // described by device configuration
    usb_setup_endpoints();

    // Present full speed device by enabling pull up on DP
    usb_hw_set->sie_ctrl = USB_SIE_CTRL_PULLUP_EN_BITS;
}

/**
 * @brief Given an endpoint configuration, returns true if the endpoint
 * is transmitting data to the host (i.e. is an IN endpoint)
 *
 * @param ep, the endpoint configuration
 * @return true
 * @return false
 */
static inline bool ep_is_tx(struct usb_endpoint_configuration *ep) {
    return ep->descriptor->bEndpointAddress & USB_DIR_IN;
}

/**
 * @brief Starts a transfer on a given endpoint.
 *
 * @param ep, the endpoint configuration.
 * @param buf, the data buffer to send. Only applicable if the endpoint is TX
 * @param len, the length of the data in buf (this example limits max len to one packet - 64 bytes)
 */
void usb_start_transfer(struct usb_endpoint_configuration *ep, uint8_t *buf, uint16_t len) {
    // We are asserting that the length is <= 64 bytes for simplicity of the example.
    // For multi packet transfers see the tinyusb port.
    assert(len <= 64);

//    printf("Start transfer of len %d on ep addr 0x%x\n", len, ep->descriptor->bEndpointAddress);

    // Prepare buffer control register value
    uint32_t val = len | USB_BUF_CTRL_AVAIL;

    if (ep_is_tx(ep)) {
        // Need to copy the data from the user buffer to the usb memory
        memcpy((void *) ep->data_buffer, (void *) buf, len);
        // Mark as full
        val |= USB_BUF_CTRL_FULL;
    }

    // Set pid and flip for next transfer
    val |= ep->next_pid ? USB_BUF_CTRL_DATA1_PID : USB_BUF_CTRL_DATA0_PID;
    ep->next_pid ^= 1u;

    *ep->buffer_control = val;
}

/**
 * @brief Send device descriptor to host
 *
 */
void usb_handle_device_descriptor(void) {
    const struct usb_device_descriptor *d = dev_config.device_descriptor;
    // EP0 in
    struct usb_endpoint_configuration *ep = usb_get_endpoint_configuration(EP0_IN_ADDR);
    // Always respond with pid 1
    ep->next_pid = 1;
    usb_start_transfer(ep, (uint8_t *) d, sizeof(struct usb_device_descriptor));
}

/**
 * @brief Send the configuration descriptor (and potentially the configuration and endpoint descriptors) to the host.
 *
 * @param pkt, the setup packet received from the host.
 */
void usb_handle_config_descriptor(volatile struct usb_setup_packet *pkt) {
    uint8_t *buf = &ep0_buf[0];

    // First request will want just the config descriptor
    const struct usb_configuration_descriptor *d = dev_config.config_descriptor;
    memcpy((void *) buf, d, sizeof(struct usb_configuration_descriptor));
    buf += sizeof(struct usb_configuration_descriptor);

    // If we more than just the config descriptor copy it all
    if (pkt->wLength >= d->wTotalLength) {
        memcpy((void *) buf, dev_config.interface_descriptor, sizeof(struct usb_interface_descriptor));
        buf += sizeof(struct usb_interface_descriptor);
        const struct usb_endpoint_configuration *ep = dev_config.endpoints;

        // Copy all the endpoint descriptors starting from EP1
        for (uint i = 2; i < USB_NUM_ENDPOINTS; i++) {
            if (ep[i].descriptor) {
                memcpy((void *) buf, ep[i].descriptor, sizeof(struct usb_endpoint_descriptor));
                buf += sizeof(struct usb_endpoint_descriptor);
            }
        }

    }

    // Send data
    // Get len by working out end of buffer subtract start of buffer
    uint32_t len = (uint32_t) buf - (uint32_t) &ep0_buf[0];
    usb_start_transfer(usb_get_endpoint_configuration(EP0_IN_ADDR), &ep0_buf[0], len);
}

/**
 * @brief Handle a BUS RESET from the host by setting the device address back to 0.
 *
 */
void usb_bus_reset(void) {
    // Set address back to 0
    dev_addr = 0;
    should_set_address = false;
    usb_hw->dev_addr_ctrl = 0;
    configured = false;
}

/**
 * @brief Send the requested string descriptor to the host.
 *
 * @param pkt, the setup packet from the host.
 */
void usb_handle_string_descriptor(volatile struct usb_setup_packet *pkt) {
    uint8_t i = pkt->wValue & 0xff;
    uint8_t len = 0;

    if (i == 0) {
        len = 4;
        memcpy(&ep0_buf[0], dev_config.lang_descriptor, len);
    } else {
        // Prepare fills in ep0_buf
        len = usb_prepare_string_descriptor(dev_config.descriptor_strings[i - 1]);
    }

    usb_start_transfer(usb_get_endpoint_configuration(EP0_IN_ADDR), &ep0_buf[0], len);
}

/**
 * @brief Sends a zero length status packet back to the host.
 */
void usb_acknowledge_out_request(void) {
    usb_start_transfer(usb_get_endpoint_configuration(EP0_IN_ADDR), NULL, 0);
}

/**
 * @brief Handles a SET_ADDR request from the host. The actual setting of the device address in
 * hardware is done in ep0_in_handler. This is because we have to acknowledge the request first
 * as a device with address zero.
 *
 * @param pkt, the setup packet from the host.
 */
void usb_set_device_address(volatile struct usb_setup_packet *pkt) {
    // Set address is a bit of a strange case because we have to send a 0 length status packet first with
    // address 0
    dev_addr = (pkt->wValue & 0xff);
    printf("Set address %d\r\n", dev_addr);
    // Will set address in the callback phase
    should_set_address = true;
    usb_acknowledge_out_request();
}

/**
 * @brief Handles a SET_CONFIGRUATION request from the host. Assumes one configuration so simply
 * sends a zero length status packet back to the host.
 *
 * @param pkt, the setup packet from the host.
 */
void usb_set_device_configuration(volatile struct usb_setup_packet *pkt) {
    // Only one configuration so just acknowledge the request
    printf("Device Enumerated\r\n");
    usb_acknowledge_out_request();
    configured = true;
}

/**
 * @brief Respond to a setup packet from the host.
 *
 */
void usb_handle_setup_packet(void) {
    volatile struct usb_setup_packet *pkt = (volatile struct usb_setup_packet *) &usb_dpram->setup_packet;
    uint8_t req_direction = pkt->bmRequestType;
    uint8_t req = pkt->bRequest;

    // Reset PID to 1 for EP0 IN
    usb_get_endpoint_configuration(EP0_IN_ADDR)->next_pid = 1u;

    if (req_direction == USB_DIR_OUT) {
        if (req == USB_REQUEST_SET_ADDRESS) {
            usb_set_device_address(pkt);
        } else if (req == USB_REQUEST_SET_CONFIGURATION) {
            usb_set_device_configuration(pkt);
        } else {
            usb_acknowledge_out_request();
            printf("Other OUT request (0x%x)\r\n", pkt->bRequest);
        }
    } else if (req_direction == USB_DIR_IN) {
        if (req == USB_REQUEST_GET_DESCRIPTOR) {
            uint16_t descriptor_type = pkt->wValue >> 8;

            switch (descriptor_type) {
                case USB_DT_DEVICE:
                    usb_handle_device_descriptor();
                    printf("GET DEVICE DESCRIPTOR\r\n");
                    break;

                case USB_DT_CONFIG:
                    usb_handle_config_descriptor(pkt);
                    printf("GET CONFIG DESCRIPTOR\r\n");
                    break;

                case USB_DT_STRING:
                    usb_handle_string_descriptor(pkt);
                    printf("GET STRING DESCRIPTOR\r\n");
                    break;

                default:
                    printf("Unhandled GET_DESCRIPTOR type 0x%x\r\n", descriptor_type);
            }
        } else {
            printf("Other IN request (0x%x)\r\n", pkt->bRequest);
        }
    }
}

/**
 * @brief Notify an endpoint that a transfer has completed.
 *
 * @param ep, the endpoint to notify.
 */
static void usb_handle_ep_buff_done(struct usb_endpoint_configuration *ep) {
    uint32_t buffer_control = *ep->buffer_control;
    // Get the transfer length for this endpoint
    uint16_t len = buffer_control & USB_BUF_CTRL_LEN_MASK;

    // Call that endpoints buffer done handler
    ep->handler((uint8_t *) ep->data_buffer, len);
}

/**
 * @brief Find the endpoint configuration for a specified endpoint number and
 * direction and notify it that a transfer has completed.
 *
 * @param ep_num
 * @param in
 */
static void usb_handle_buff_done(uint ep_num, bool in) {
    uint8_t ep_addr = ep_num | (in ? USB_DIR_IN : 0);
//    printf("EP %d (in = %d) done\n", ep_num, in);
    for (uint i = 0; i < USB_NUM_ENDPOINTS; i++) {
        struct usb_endpoint_configuration *ep = &dev_config.endpoints[i];
        if (ep->descriptor && ep->handler) {
            if (ep->descriptor->bEndpointAddress == ep_addr) {
                usb_handle_ep_buff_done(ep);
                return;
            }
        }
    }
}

/**
 * @brief Handle a "buffer status" irq. This means that one or more
 * buffers have been sent / received. Notify each endpoint where this
 * is the case.
 */
static void usb_handle_buff_status() {
    uint32_t buffers = usb_hw->buf_status;
    uint32_t remaining_buffers = buffers;

    uint bit = 1u;
    for (uint i = 0; remaining_buffers && i < USB_NUM_ENDPOINTS * 2; i++) {
        if (remaining_buffers & bit) {
            // clear this in advance
            usb_hw_clear->buf_status = bit;
            // IN transfer for even i, OUT transfer for odd i
            usb_handle_buff_done(i >> 1u, !(i & 1u));
            remaining_buffers &= ~bit;
        }
        bit <<= 1u;
    }
}

/**
 * @brief USB interrupt handler
 *
 */
/// \tag::isr_setup_packet[]
void isr_usbctrl(void) {
    // USB interrupt handler
    uint32_t status = usb_hw->ints;
    uint32_t handled = 0;

    // Setup packet received
    if (status & USB_INTS_SETUP_REQ_BITS) {
        handled |= USB_INTS_SETUP_REQ_BITS;
        usb_hw_clear->sie_status = USB_SIE_STATUS_SETUP_REC_BITS;
        usb_handle_setup_packet();
    }
/// \end::isr_setup_packet[]

    // Buffer status, one or more buffers have completed
    if (status & USB_INTS_BUFF_STATUS_BITS) {
        handled |= USB_INTS_BUFF_STATUS_BITS;
        usb_handle_buff_status();
    }

    // Bus is reset
    if (status & USB_INTS_BUS_RESET_BITS) {
        printf("BUS RESET\n");
        handled |= USB_INTS_BUS_RESET_BITS;
        usb_hw_clear->sie_status = USB_SIE_STATUS_BUS_RESET_BITS;
        usb_bus_reset();
    }

    if (status ^ handled) {
        panic("Unhandled IRQ 0x%x\n", (uint) (status ^ handled));
    }
}

/**
 * @brief EP0 in transfer complete. Either finish the SET_ADDRESS process, or receive a zero
 * length status packet from the host.
 *
 * @param buf the data that was sent
 * @param len the length that was sent
 */
void ep0_in_handler(uint8_t *buf, uint16_t len) {
    if (should_set_address) {
        // Set actual device address in hardware
        usb_hw->dev_addr_ctrl = dev_addr;
        should_set_address = false;
    } else {
        // Receive a zero length status packet from the host on EP0 OUT
        struct usb_endpoint_configuration *ep = usb_get_endpoint_configuration(EP0_OUT_ADDR);
        usb_start_transfer(ep, NULL, 0);
    }
}

void ep0_out_handler(uint8_t *buf, uint16_t len) {
}
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
int main(void) {

	stdio_init_all();
	printf("Musli initializing ...\n");
	printf("usb_device_init ...\n");
	usb_device_init();

	printf("loading spi_pio ...\n");
	spi_pio_offset = pio_add_program(spi_pio.pio, &spi_cpha0_program);
	printf("loaded PIO program at %d\n", spi_pio_offset);

	init_ldprog();

	printf("waiting for usb configuration ...\n");
	// Wait until configured
	while (!configured) {
		tight_loop_contents();
	}

	printf("waiting for data from host ...\n");
	// Get ready to rx from host
	usb_start_transfer(usb_get_endpoint_configuration(EP1_OUT_ADDR), NULL, 64);

	// Everything is interrupt driven so just loop here
	while (1) {
		tight_loop_contents();
	}

	return 0;

}

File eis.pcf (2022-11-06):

# Eis V0
# ------

set_io CLK_48	L5		# this is CLK_RP

set_io LED_A	G3

# PMOD_A
set_io PMOD_A1  L4
set_io PMOD_A2  L1
set_io PMOD_A3  K3
set_io PMOD_A4  J4
set_io PMOD_A7  L3
set_io PMOD_A8  K5
set_io PMOD_A9  K4
set_io PMOD_A10 J3

# UART on PMODA
set_io UART0_RTS  L4
set_io UART0_RX   L1
set_io UART0_TX   K3
set_io UART0_CTS  J4

# --

# DDMI
set_io DDMI_D0_P	H2
set_io DDMI_D0_N	H1
set_io DDMI_D1_P	J2
set_io DDMI_D1_N	J1
set_io DDMI_D2_P	K2
set_io DDMI_D2_N	K1
set_io DDMI_CK_P	G2
set_io DDMI_CK_N	G1

# RP2040
set_io RP_INT		K7
set_io RP_TX		L7
set_io RP_RX		L8

# MMOD/SD SPI BUS
set_io SPI_SS_FLASH  K10
set_io SPI_SS_SD		J8
set_io SPI_SS_RP		J7
set_io SPI_SCK       L10
set_io SPI_MISO      J9		# CSPI_SI
set_io SPI_MOSI      K9		# CSPI_SO

# STATIC RAM
set_io SRAM_A0		C1
set_io SRAM_A1		D1
set_io SRAM_A2		E1
set_io SRAM_A3		C2
set_io SRAM_A4		D2
set_io SRAM_A5		C4
set_io SRAM_A6		C3
set_io SRAM_A7		C7
set_io SRAM_A8		A7
set_io SRAM_A9		A8
set_io SRAM_A10	A9
set_io SRAM_A11	A10
set_io SRAM_A12	B7
set_io SRAM_A13	B8
set_io SRAM_A14	B6
set_io SRAM_A15	B9
set_io SRAM_A16	C8
set_io SRAM_A17	C9

set_io SRAM0_D0		E3
set_io SRAM0_D1		F1
set_io SRAM0_D2		F2
set_io SRAM0_D3		F3
set_io SRAM0_D4		D7
set_io SRAM0_D5		E2
set_io SRAM0_D6		A11
set_io SRAM0_D7		F4
set_io SRAM0_D8		A2
set_io SRAM0_D9		A3
set_io SRAM0_D10	B3
set_io SRAM0_D11	A4
set_io SRAM0_D12	B4
set_io SRAM0_D13	B5
set_io SRAM0_D14	A5
set_io SRAM0_D15	A6

set_io SRAM0_CE		D3
set_io SRAM0_WE		D5
set_io SRAM0_OE		B1
set_io SRAM0_LB		A1
set_io SRAM0_UB		B2

# OPI PSRAM
set_io HRAM_ADQ0	J11
set_io HRAM_ADQ1	G10
set_io HRAM_ADQ2	G9
set_io HRAM_ADQ3	H10
set_io HRAM_ADQ4	F9
set_io HRAM_ADQ5	K11
set_io HRAM_ADQ6	J10
set_io HRAM_ADQ7	G11
set_io HRAM_DQ8	F10
set_io HRAM_DQ9	E11
set_io HRAM_DQ10	D11
set_io HRAM_DQ11	C11
set_io HRAM_DQ12	B11
set_io HRAM_DQ13	E8
set_io HRAM_DQ14	D9
set_io HRAM_DQ15	H11
set_io HRAM_DQS0	F11
set_io HRAM_DQS1	E9
set_io HRAM_CK		E10
set_io HRAM_CE		D10

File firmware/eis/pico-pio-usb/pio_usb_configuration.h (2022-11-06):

#pragma once

typedef enum {
  PIO_USB_PINOUT_DPDM = 0,  // DM = DP +1
  PIO_USB_PINOUT_DMDP,      // DM = DP -1
} PIO_USB_PINOUT;

typedef struct {
  uint8_t pin_dp;
  PIO_USB_PINOUT pinout;
  uint8_t pio_tx_num;
  uint8_t sm_tx;
  uint8_t tx_ch;
  uint8_t pio_rx_num;
  uint8_t sm_rx;
  uint8_t sm_eop;
  void* alarm_pool;
  int8_t debug_pin_rx;
  int8_t debug_pin_eop;
} pio_usb_configuration_t;

#ifndef PIO_USB_DP_PIN_DEFAULT
#define PIO_USB_DP_PIN_DEFAULT 28
#endif

#ifndef PIO_USB_PINOUT_DEFAULT
#define PIO_USB_PINOUT_DEFAULT PIO_USB_PINOUT_DPDM
#endif

//#define PIO_USB_DM_PIN_DEFAULT (PIO_USB_DP_PIN_DEFAULT - 1)

#define PIO_USB_TX_DEFAULT 0
#define PIO_SM_USB_TX_DEFAULT 0
#define PIO_USB_DMA_TX_DEFAULT 0

#define PIO_USB_RX_DEFAULT 1
#define PIO_SM_USB_RX_DEFAULT 0
#define PIO_SM_USB_EOP_DEFAULT 1

#define PIO_USB_DEBUG_PIN_NONE (-1)

#define PIO_USB_DEFAULT_CONFIG                                             \
  {                                                                        \
    PIO_USB_DP_PIN_DEFAULT, PIO_USB_PINOUT_DEFAULT, PIO_USB_TX_DEFAULT,    \
        PIO_SM_USB_TX_DEFAULT, PIO_USB_DMA_TX_DEFAULT, PIO_USB_RX_DEFAULT, \
        PIO_SM_USB_RX_DEFAULT, PIO_SM_USB_EOP_DEFAULT, NULL,               \
        PIO_USB_DEBUG_PIN_NONE, PIO_USB_DEBUG_PIN_NONE                     \
  }

#define PIO_USB_EP_POOL_CNT 32
#define PIO_USB_DEV_EP_CNT 16
#define PIO_USB_DEVICE_CNT 4
#define PIO_USB_HUB_PORT_CNT 8
#define PIO_USB_ROOT_PORT_CNT 2

#define PIO_USB_EP_SIZE 64

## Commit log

2022-11-10 3d printable case
    [eis.scad]
2022-11-10 make keyboard work when using stand-alone power supply
2023-02-21 add hardware notes
    [eis.scad]
2023-04-25 improve fit
    [eis.scad]
2023-04-26 add pcb
    [eis.kicad_pcb, eis.kicad_sch]
